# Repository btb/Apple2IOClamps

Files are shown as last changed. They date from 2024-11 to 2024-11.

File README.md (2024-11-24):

# Apple II Rear I/O Clamps

Clamps for fixing connectors to the rear of an Apple ][

## Parts

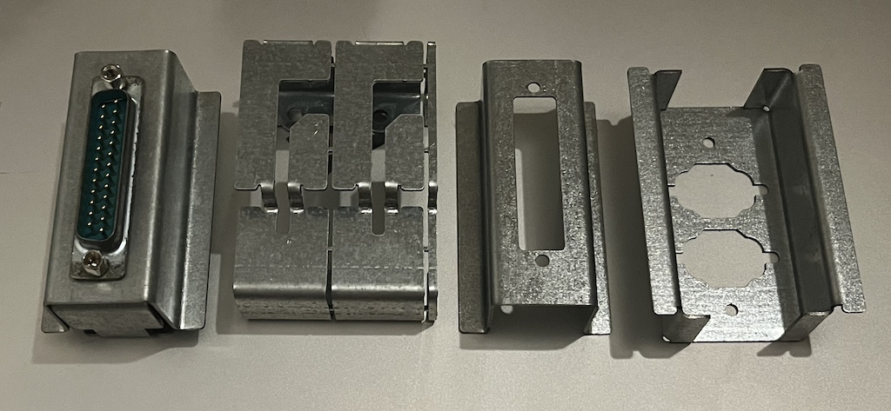
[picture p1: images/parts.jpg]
Parts


### Rear Clamp

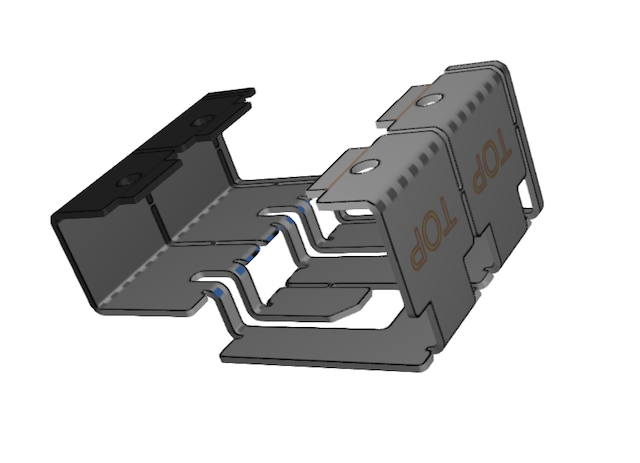
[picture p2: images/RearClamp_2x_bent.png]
RearClamp


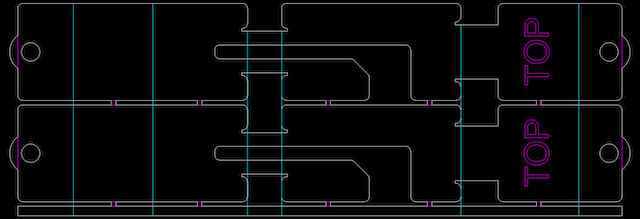
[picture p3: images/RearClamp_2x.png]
RearClamp


For use with both the 25-pin and 9-pin front clamps.

Made from .048" galvanized steel.

Magenta lines are for "single-line" laser etching. The semicircular areas at the ends are for cutting or grinding away AFTER the self-clinching nuts have been pressed in.

The round holes are for #4-40 self-clinching nuts (PEM S-440-1ZI) to be inserted after cutting and bending. The vendor I used didn't have tooling that could reach in between the bends to do the insertion, so I pressed them in after delivery using Vise Grips, which turned out fine. It probably wouldn't be that hard to make a custom jig for this.

#### Procedure

1. Laser cut and bend on the cyan lines, according to the rendering above.
2. Separate the two clamps with a saw, and discard the bottom stabilizing strip.
3. Press in the self-clinching nuts, they go on the "inside" of the bracket.
4. Cut or grind off the extra radius around the nuts.

### Front Clamp, 25-pin

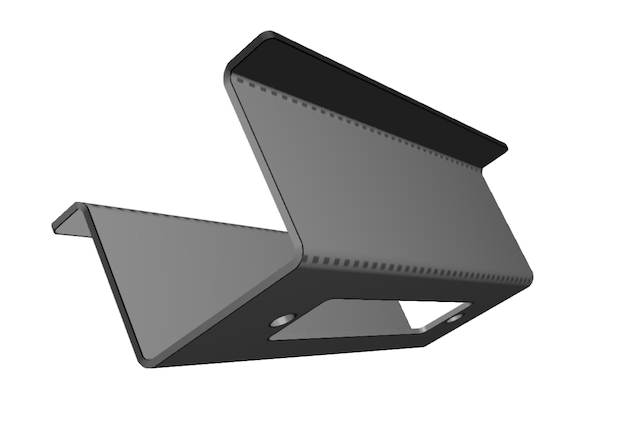
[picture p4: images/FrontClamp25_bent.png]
FrontClamp25


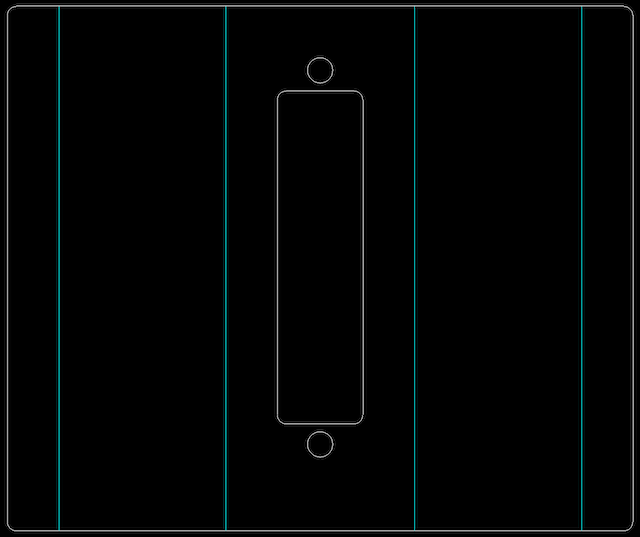
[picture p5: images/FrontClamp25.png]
FrontClamp25


Made from .036" galvanized steel.

#### Procedure

1. Laser cut and bend on the cyan lines, according to the rendering above.

### Front Clamp, 9-pin x 2

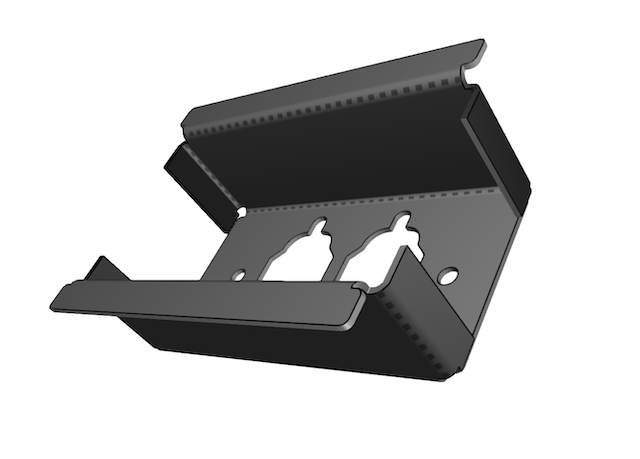
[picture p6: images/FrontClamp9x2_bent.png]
FrontClamp9x2


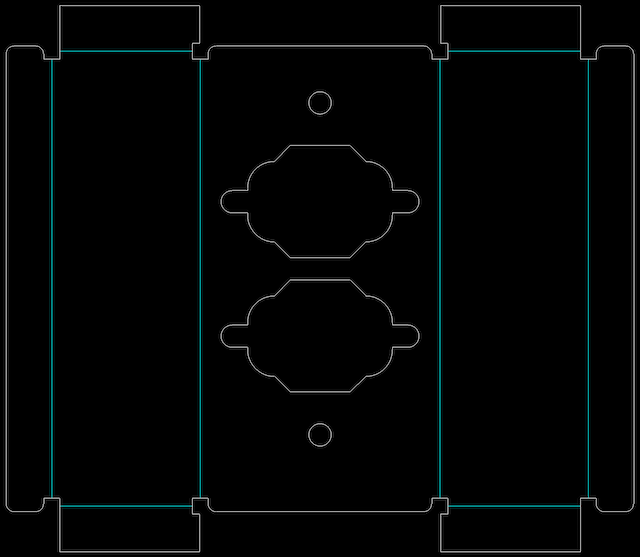
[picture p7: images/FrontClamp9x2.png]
FrontClamp9x2


Made from .036" galvanized steel.

#### Procedure

1. Laser cut and bend on the cyan lines, according to the rendering above.

### Nut Plate

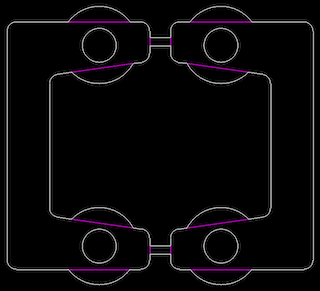
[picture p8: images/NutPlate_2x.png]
NutPlate


These plates are a convenient way to fasten the 9-pin connectors.

Made from .059" galvanized steel.

Magenta lines are for "single-line" laser etching. The semicircular areas are for cutting or grinding away AFTER the self-clinching nuts have been pressed in.

The round holes are for #4-40 self-clinching nuts (PEM S-440-1ZI) to be inserted after cutting.

#### Procedure

1. Laser cut.
2. Press in the self-clinching nuts.
3. Separate the two pieces with a saw and deburr.
4. Cut or grind off the extra radius around the nuts.

## Usage / More Info

The 25-pin version was bundled with the Super Serial Card. See assembly instructions in the [Super Serial Card manual](https://archive.org/details/Apple_II_Super_Serial_Card_1981_Apple/page/n6/mode/1up).

The 9-pin version was bundled with the Game Port Adapter Kit. I have yet to find those instructions online.

I believe there was also a dual 19-pin version, for use with disk drive adapters, but I haven't modeled that one, or found any good scans or photos.

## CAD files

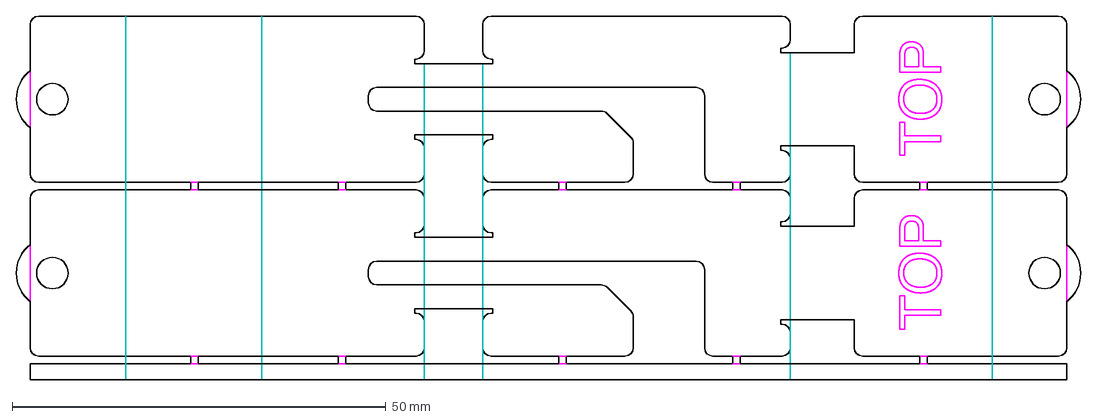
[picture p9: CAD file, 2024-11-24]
RearClamp_2x.dxf
142.3 x 48.6 mm

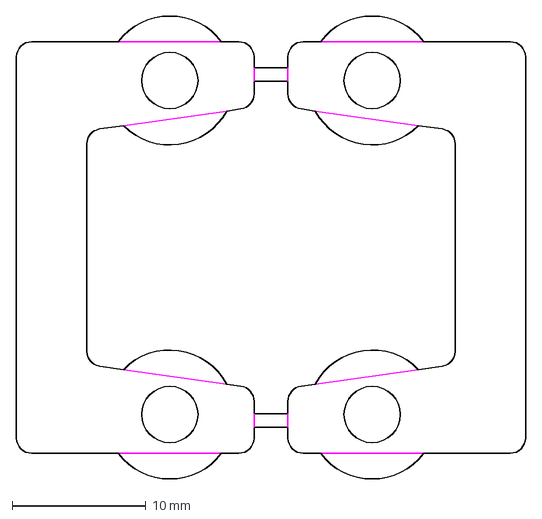
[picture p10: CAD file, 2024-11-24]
NutPlate_2x.dxf
38.1 x 34.6 mm

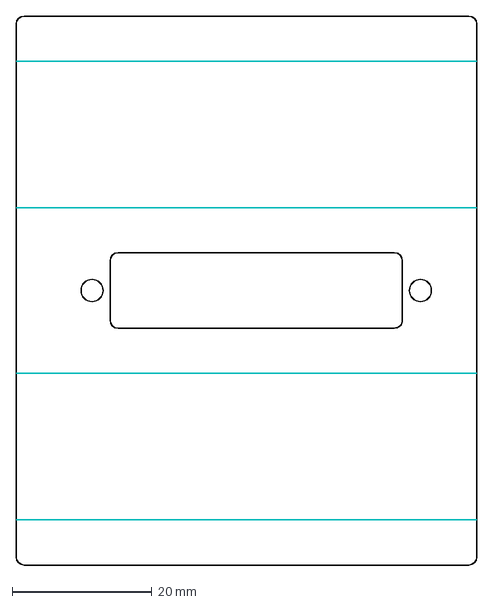
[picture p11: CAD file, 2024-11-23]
FrontClamp25.dxf
66.0 x 78.7 mm

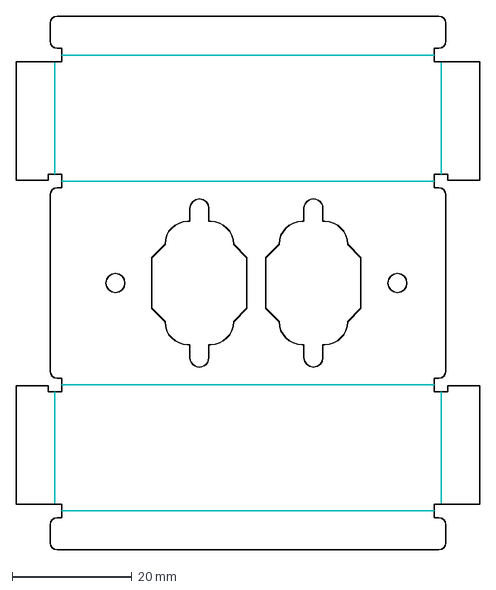
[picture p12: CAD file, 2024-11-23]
FrontClamp9x2.dxf
77.4 x 89.1 mm

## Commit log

2024-11-23 use cyan for all bends
    [FrontClamp25.dxf]
2024-11-24 rename etch layer
    [NutPlate_2x.dxf, RearClamp_2x.dxf]
